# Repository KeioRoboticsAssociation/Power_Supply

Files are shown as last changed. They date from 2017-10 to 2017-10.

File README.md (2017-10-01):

# 電源基板
## 経緯
ロボットによく使う電源をまとめて出力できる基板があると便利という話があったので作りました。

## 仕様
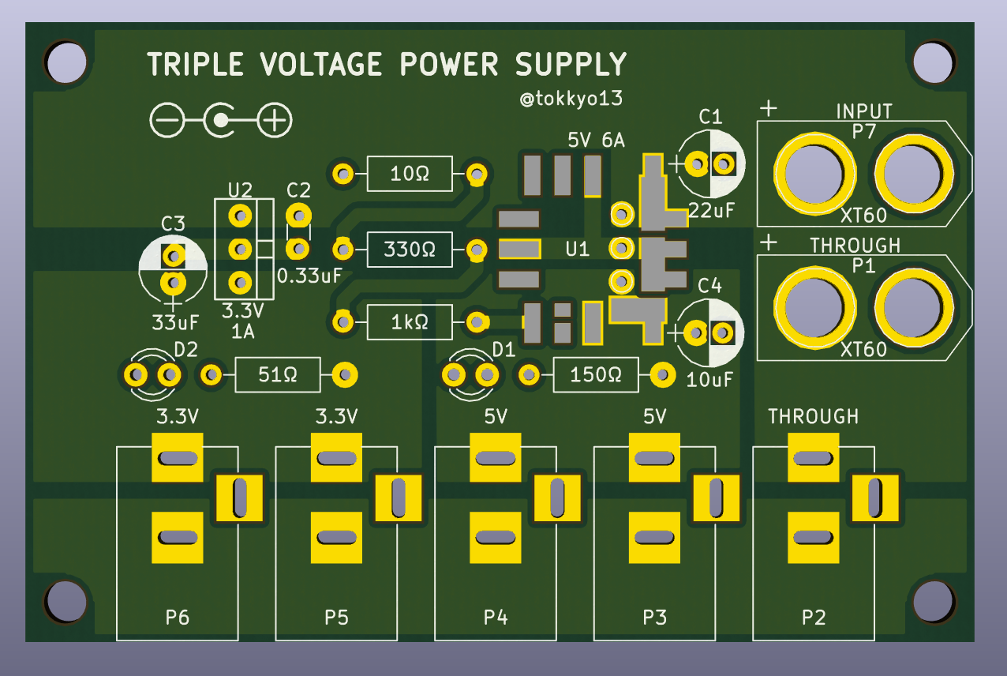
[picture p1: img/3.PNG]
外観

使っている素子の詳しいことは以下のデータシートを読みましょう。  
[OKL-T/6-W12](http://akizukidenshi.com/download/ds/murata/OKL_T6_W12.pdf)  
[TA48033S](http://akizukidenshi.com/download/ta48033s.pdf)

|コネクタ|機能|
|:-|:-|
|P1|12V出力(XT60コネクタ・オス)|
|P2|12V出力(DCコネクタ・メス)|
|P3・P4|5V出力(DCコネクタ・メス), 合計6Aまで|
|P5・P6|3.3V出力(DCコネクタ・メス), 合計1Aまで|
|P7|12V入力(XT60コネクタ・オス)|

DCDCコンバータ(U1)は表面実装なので少しはんだ付けが難しい。なので5V電源に要求される電流が少ない場合、3端子レギュレータを代わりに実装できるようにスルーホールも開けてある。

DCDCコンバータを使う場合は、10Ω, 330Ω, 1kΩの3つの抵抗の合計値を変更すれば、出力電圧を0.591V〜5.5Vの範囲で変更できる。値の変え方はデータシートに書いてある。

THROUGH端子(P1・P2)は内部的には電源入力端子と同じなので、実は電源入力端子としても使える。例えばパソコンのACアダプタをP2に繋いで5V電源を取り出したり出来る。

## 部品表
|番号|部品名|個数|備考|
|:-|:-|:-|:-|
|P1,P7|XT60オス|2|オス・メスを間違えやすいので気をつけて。ラジコンショップで売ってる|
|P2,P3,P4,P5,P6|基板取り付け用DCジャック|5|センタープラス。|
|C1|22uF, 16V|1|電解コンデンサ|
|C2|(0.33uF)|0|U2のセットに含まれてるので買わなくて良い。|
|C3|(33uF)|0|U2のセットに含まれてるので買わなくて良い。|
|C4|10uF, 16V|1|電解コンデンサ|
|D1・D2|3mm赤色LED 70° OSR5JA3Z74A|2|別にこれじゃなくてもいい。|
|U1|DCDCコンバータ OKL-T/6-W12|1|表面実装のやつ。|
|U2|TA48033S|1セット|コンデンサがセットになってるやつが秋月で売ってる。|
|抵抗|抵抗値は基板に書いてある|合計5個||

※注意：はんだ付けするときは背の低い部品からつけていくと良い。U1は最初につけるべし。

## イメージ
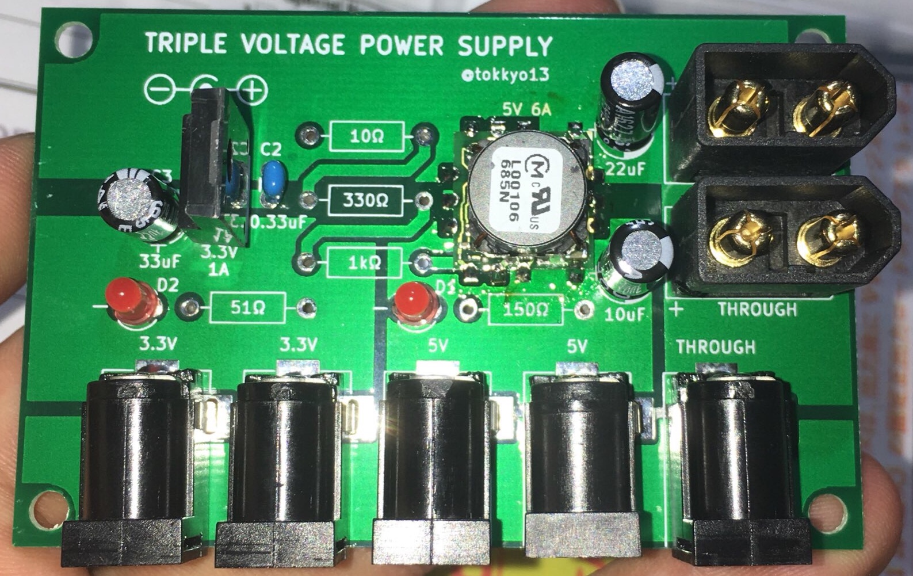
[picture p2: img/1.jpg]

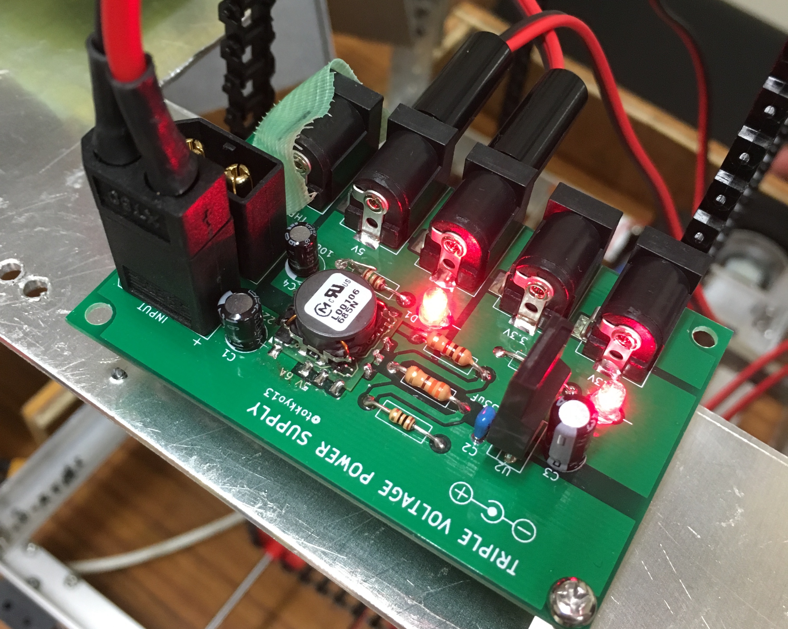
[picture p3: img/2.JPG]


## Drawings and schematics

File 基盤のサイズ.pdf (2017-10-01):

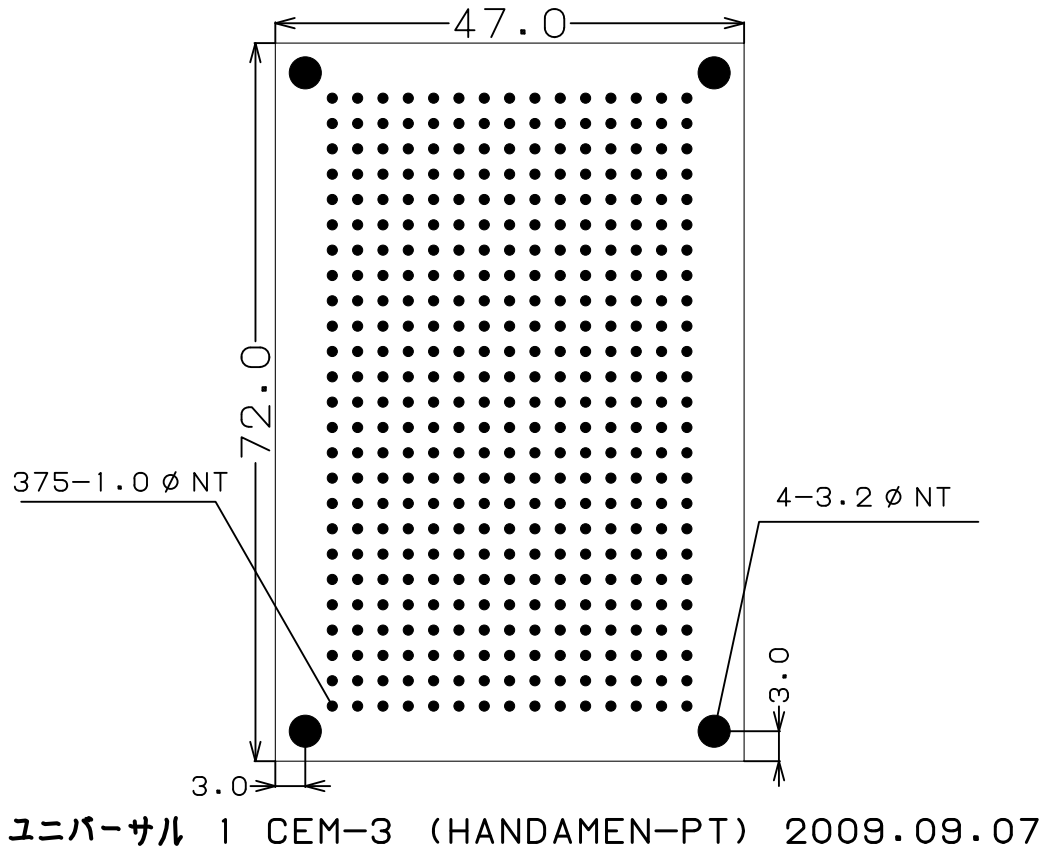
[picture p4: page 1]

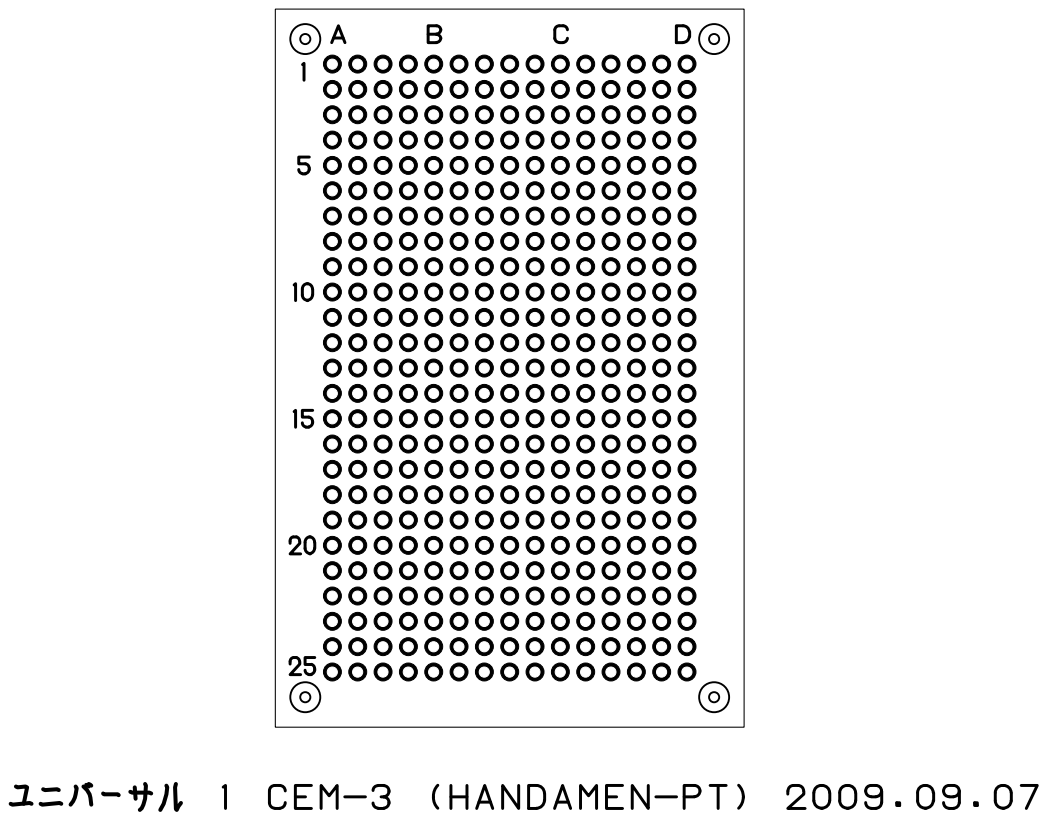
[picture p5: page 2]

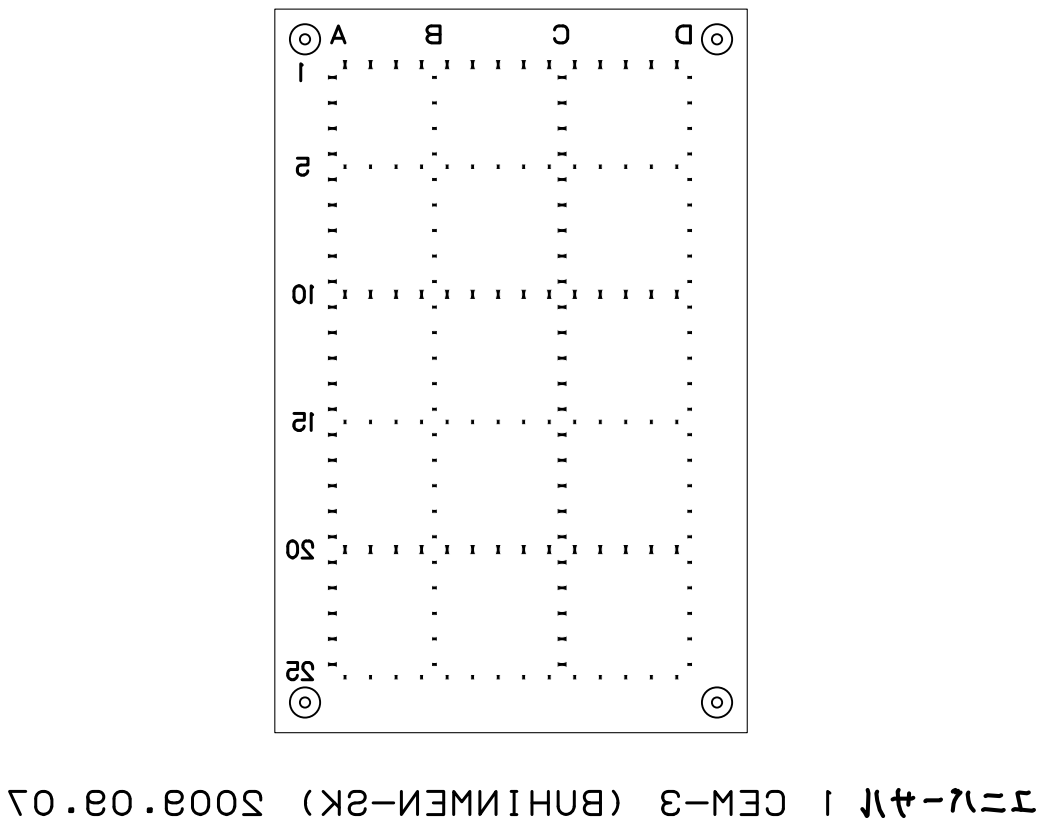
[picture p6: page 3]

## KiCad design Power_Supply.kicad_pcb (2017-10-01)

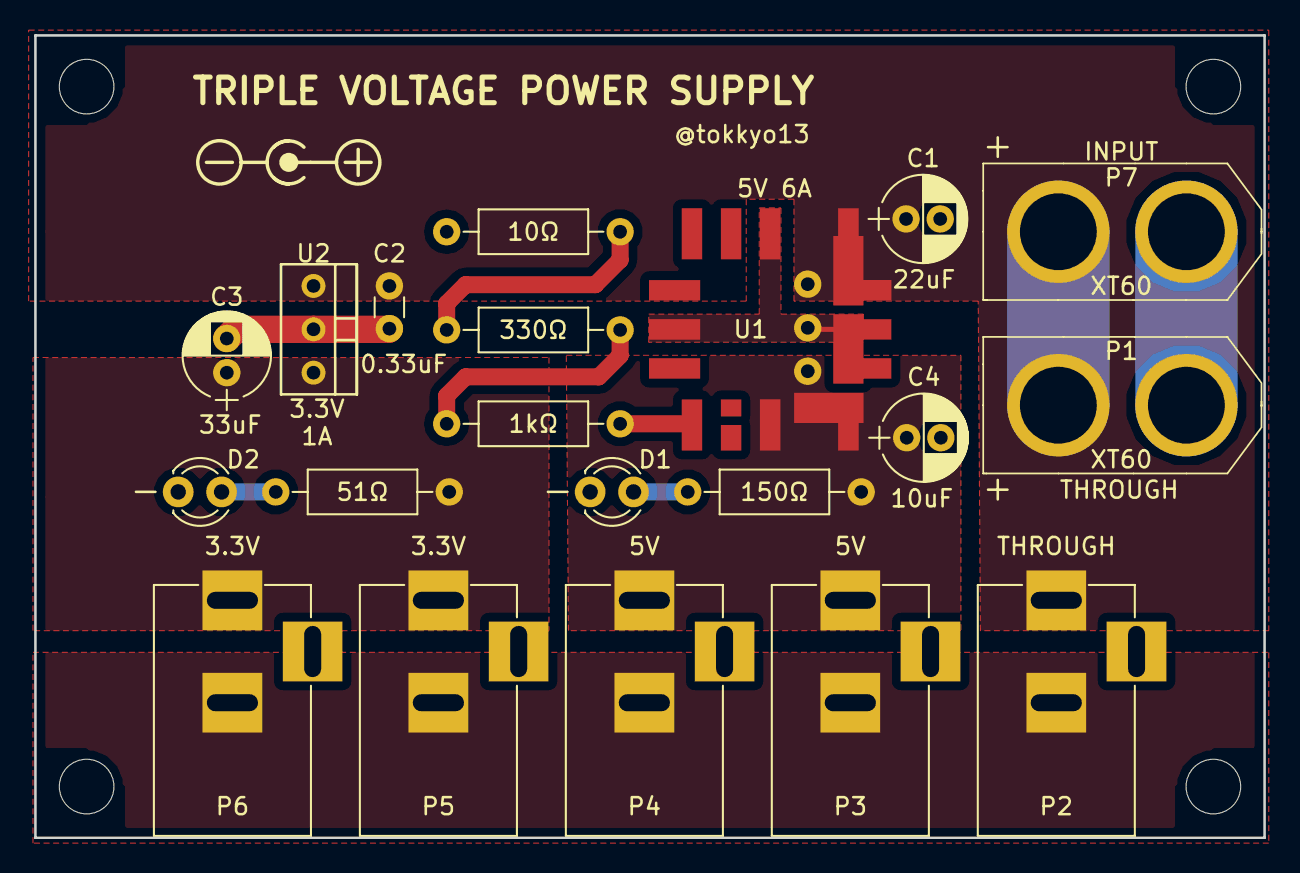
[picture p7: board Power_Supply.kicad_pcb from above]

Board: 2 copper layers, 72.0 x 47.0 mm, 20 parts (0 on the bottom side), 9 nets.

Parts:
1kΩ: 1k; R_Axial_DIN0207_L6.3mm_D2.5mm_P10.16mm_Horizontal
10Ω: 10; R_Axial_DIN0207_L6.3mm_D2.5mm_P10.16mm_Horizontal
51Ω: 51; R_Axial_DIN0207_L6.3mm_D2.5mm_P10.16mm_Horizontal
150Ω: 150; R_Axial_DIN0207_L6.3mm_D2.5mm_P10.16mm_Horizontal
330Ω: 330; R_Axial_DIN0207_L6.3mm_D2.5mm_P10.16mm_Horizontal
C1: 22uF; CP_Radial_D5.0mm_P2.00mm
C2: 0.33uF; C_Disc_D3.0mm_W1.6mm_P2.50mm
C3: 33uF; CP_Radial_D5.0mm_P2.00mm
C4: 10uF; CP_Radial_D5.0mm_P2.00mm
D1, D2: LED; LED_D3.0mm
P1, P7: CONN_01X02; XT60
P2, P3, P4, P5, P6: CONN_01X02; BARREL_JACK
U1: OKL-T/6-W12; DCDC-murata-6A
U2: NCP1117ST33T3G; OldSowjetaera_Transistor_Type-I_SmallPads

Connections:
GND: 10Ω.2, C1.2, C2.2, C3.2, C4.2, D1.1, D2.1, P1.1, P2.2, P3.2, P4.2, P5.2, P6.2, P7.2, U1.1, U1.3, U1.7, U2.1
unnamed: 150Ω.1, D1.2
unnamed: 51Ω.1, D2.2
unnamed: 1kΩ.1, U1.6
unnamed: 1kΩ.2, 330Ω.1
unnamed: 10Ω.1, 330Ω.2
V3.3: 51Ω.2, C3.1, P5.1, P6.1, U2.2
V5: 150Ω.2, C4.1, P3.1, P4.1, U1.4, U1.5
V12: C1.1, C2.1, P1.2, P2.1, P7.1, U1.2, U2.3
